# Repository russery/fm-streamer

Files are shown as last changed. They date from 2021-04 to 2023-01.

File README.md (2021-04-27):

# FM Streamer
Are there not a lot of good FM radio stations in your vicinity? Have you ever wished you could receive your hometown station on your FM radio while you're away? Well this is the project for you!

This is a simple ESP32/ESP8266 project that grabs an MP3 internet stream and bridges it to an FM transmitter, so that you can listen to the stream on your old-school FM radio.

# Setup
If you're on Linux or Mac (or any system with GNU Make installed), install [arduino-cli](https://github.com/arduino/arduino-cli). This project is set up to work out of the box with it, and this will save you having to set up the ESP32/ESP8266 and required libraries in your Arduino IDE.

1. Run `make config-tools` to install libraries and ESP32/ESP8266 core.
1. Rename `arduino_secrets.h.example` to `arduino_secrets.h` and change the wifi SSID and password in it to match the network you wish to attach to.
1. If you want to change the radio streams, edit them in the `StationList` struct in fm-streamer.ino.
1. Power on your board, connect its serial port to your computer, and see how the serial port comes up on your computer (e.g., `/dev/cu.usbserial-xxxx` or `COM1`, etc.). You'll use this value in the next step
1. Run `make program SERIAL_PORT=<serialport> MCU_TYPE=<esp32|esp8266>` (replacing \<serialport\> with the name of the serial port from the previous step, and using either "esp32" or "esp8266" as the MCU_TYPE) to compile the code and upload it to your board.

# Usage
Once you've followed the above steps and your board is programmed, the FM Streamer should connect to your wifi network, begin streaming the first mp3 stream in `StationList` (defined in webserver.h), and automatically broadcast over FM. There is a status output on the serial console that will tell you what's going on with the board as well.

I've implemented a web interface to the FM Streamer that allows you to control the station, volume, and transmit power of the FM Streamer. Note that this doesn't work on the ESP8266, as it runs out of RAM between the web server and audio streaming. However, it works well on the ESP32. Here's what it looks like:

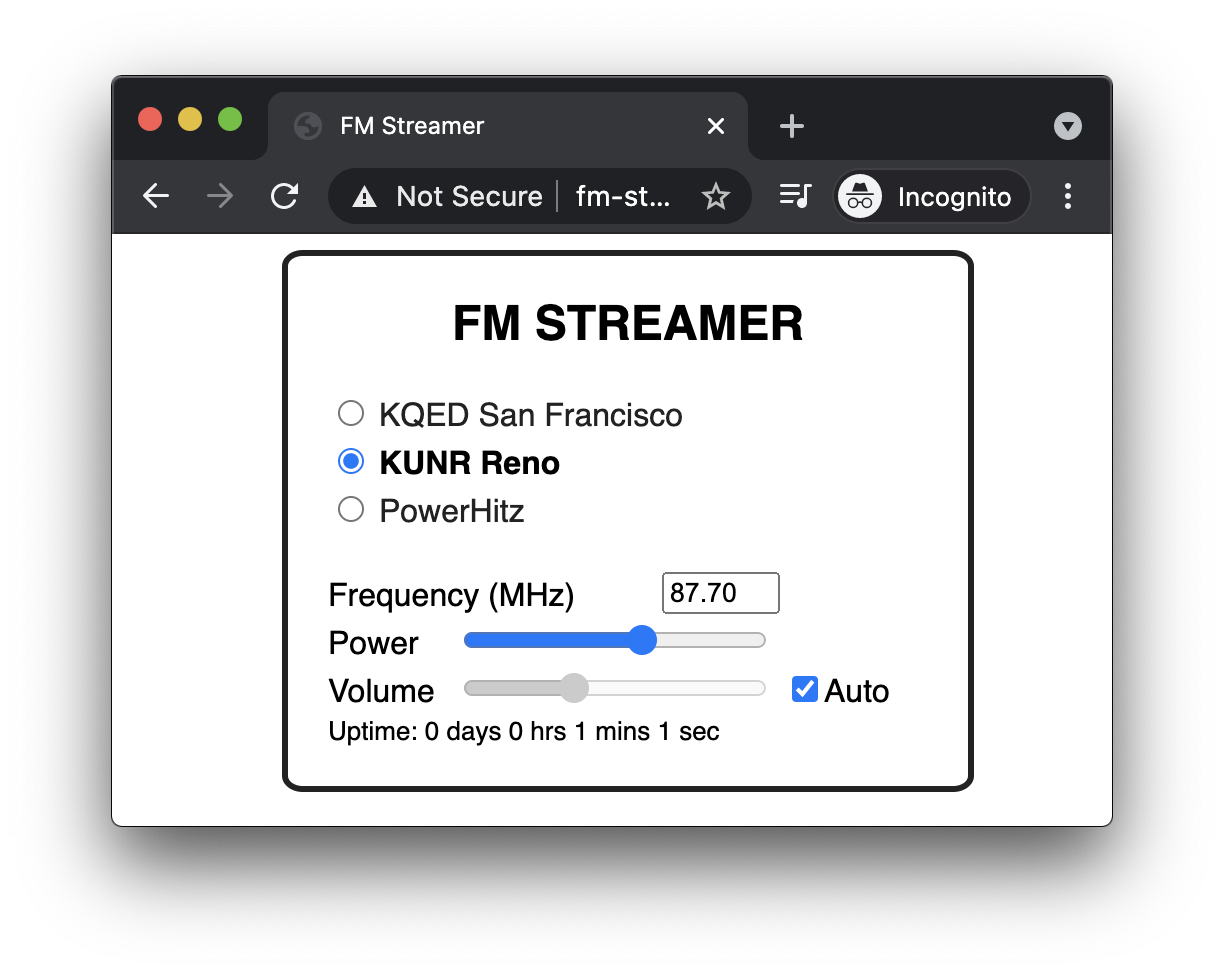
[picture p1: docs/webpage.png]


---

# Under the Hood
This project consists of three hardware components:
1. [ESP32 dev board](https://www.amazon.com/dp/B08D5ZD528) or [ESP3266 NodeMCU v1.0](https://www.amazon.com/gp/product/B010O1G1ES/)
1. [Adafruit UDA1334A I2S Stereo DAC breakout board](https://www.adafruit.com/product/3678)
1. [Adafruit Si4713 FM Transmitter breakout board](https://www.adafruit.com/product/1958)

## Hardware
These are wired together like so (for the ESP32):

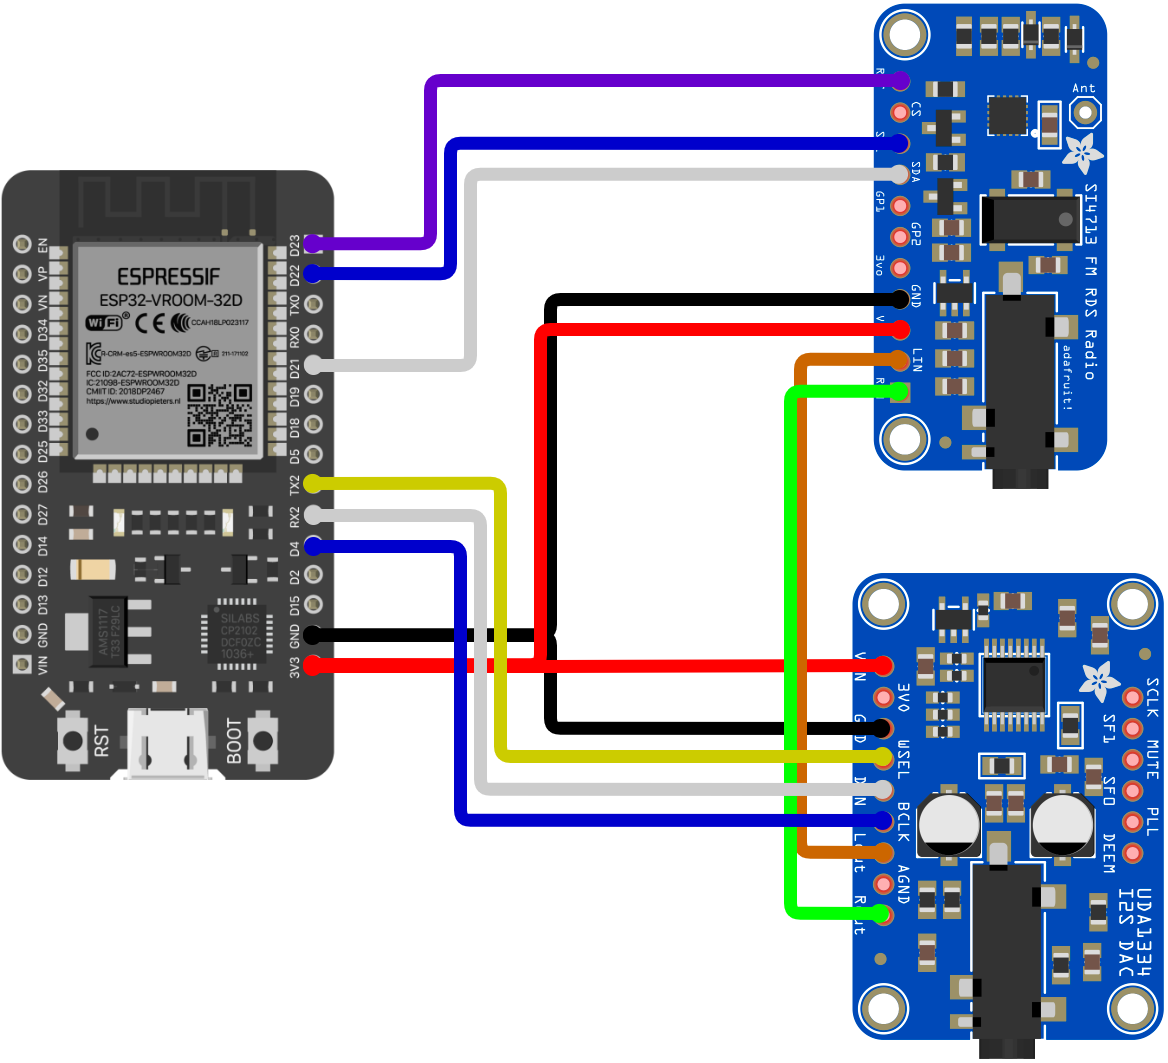
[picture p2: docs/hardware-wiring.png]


Everything is powered from the ESP32 board's 3.3V output. The Si4713 FM transmitter is connected to the ESP32 over I2C, the UDA1334 DAC is connected to it over I2S, and then the UDA1334 DAC outputs audio to the Si4713 transmitter via analog stereo audio.

I also wired a 4.7kΩ resistor from each of the DAC's analog audio outputs to GND to provide a bit of loading for it. I found that this helped reduce noise and clipping on the FM transmitter's input, although I did not experiment much with values or whether this is truly necessary.

## Software
The software makes use of the [ESP8266Audio](https://github.com/earlephilhower/ESP8266Audio) library and [Adafruit's Si4713](https://github.com/adafruit/Adafruit-Si4713-Library) driver. The webserver uses the [ESPAsynWebserver](https://github.com/me-no-dev/ESPAsyncWebServer/) library.

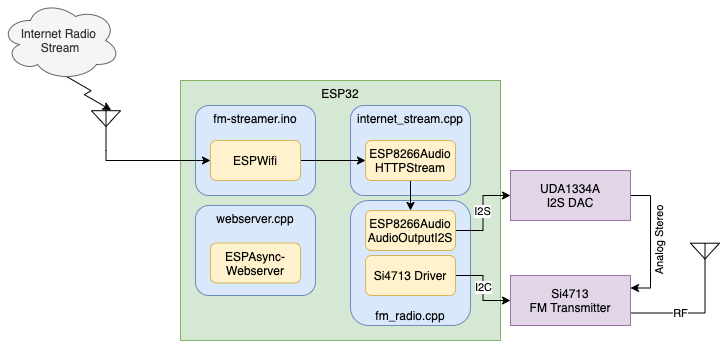
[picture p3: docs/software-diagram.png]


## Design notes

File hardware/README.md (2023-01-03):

# REV0 Hardware

## Hardware Errata
- USB connector backwards
- Silkscreen overlap on some components
- R21 puts chip in SPI mode... should be DNP'd

I2S format:
16-bit
Normal clock (rising edge)

TODO:
- fix hardware errata
- update top level readme with board images and latest hardware config

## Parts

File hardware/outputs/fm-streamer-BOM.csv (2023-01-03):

Reference | Quantity | Value | Footprint | Datasheet | MFG | MPN
C1 C13 C15 C18 | 4 | 0.1u | Capacitor_SMD:C_0402_1005Metric | ~ | Murata | GCM155R71C104KA55J
C4 C5 C6 C7 C8 C9 C10 C11 C17 | 9 | 22n | Capacitor_SMD:C_0402_1005Metric | ~ | Murata | GCM155R71E223KA55J
C2 C3 C12 C14 C16 C19 C20 C21 C22 C23 | 10 | 10u | Capacitor_SMD:C_0603_1608Metric | ~ | Murata | GRT188C81A106ME13D
J1 | 1 | USB_A | Connector_USB:USB_A_Plug_Molex_0480371000_90_deg_mount | ~ | Molex | 0480371000
L1 | 1 | 120n | Inductor_SMD:L_0603_1608Metric | ~ | Murata | LQW18ANR12G00D
R13 | 1 | 1 | Resistor_SMD:R_0402_1005Metric | ~ | Panasonic | ERJ-2BQJ1R0X
R1 R2 R14 R28 R29 R30 | 6 | 0 | Resistor_SMD:R_0402_1005Metric | ~ | Stackpole | RMCF0402ZT0R00
R15 R16 R18 R19 R20 R21 | 6 | 10k | Resistor_SMD:R_0402_1005Metric | ~ | Panasonic | ERJ-2RKF1002X
R24 R25 | 2 | 220k | Resistor_SMD:R_0402_1005Metric | ~ | Panasonic | ERJ-2RKF2203X
R4 R5 R6 R7 R8 R9 R10 R11 R17 R22 R23 R26 R27 | 13 | 100 | Resistor_SMD:R_0402_1005Metric | ~ | Panasonic | ERJ-2RKF1000X
R3 R12 | 2 | 4.7k | Resistor_SMD:R_0402_1005Metric | ~ | Panasonic | ERJ-2RKF4701X
TP1 | 1 | TestPoint | TestPoint:TestPoint_THTPad_D2.0mm_Drill1.0mm | ~ | ~ | ~
U1 | 1 | ESP32_DevKit_V1_DOIT | esp32_devkit_v1_doit:esp32_devkit_v1_doit | https://www.amazon.com/gp/product/B08D5ZD528/ | Amazon | B08D5ZD528
U2 | 1 | PCM1772PWR | footprints:PCM1772PWR |  | Texas Instruments | PCM1772PWR
U3 | 1 | SI4721 | SI4721:QFN-20-3X3MM |  | Silicon Labs | SI4721-B20-GM

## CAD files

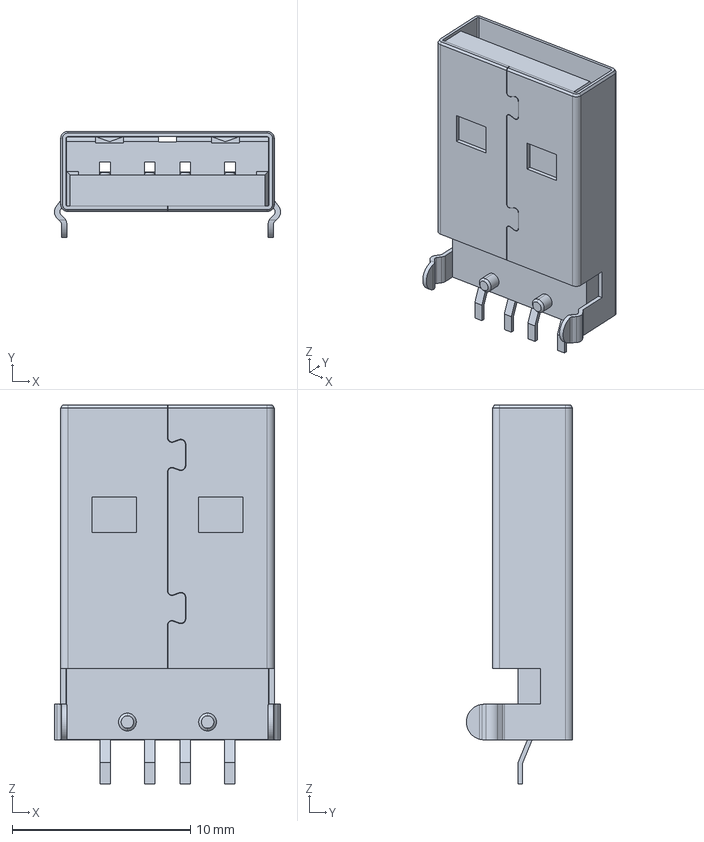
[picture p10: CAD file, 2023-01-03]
hardware/resources/molex/480371000.stp
12.7 x 5.97 x 21.3 mm

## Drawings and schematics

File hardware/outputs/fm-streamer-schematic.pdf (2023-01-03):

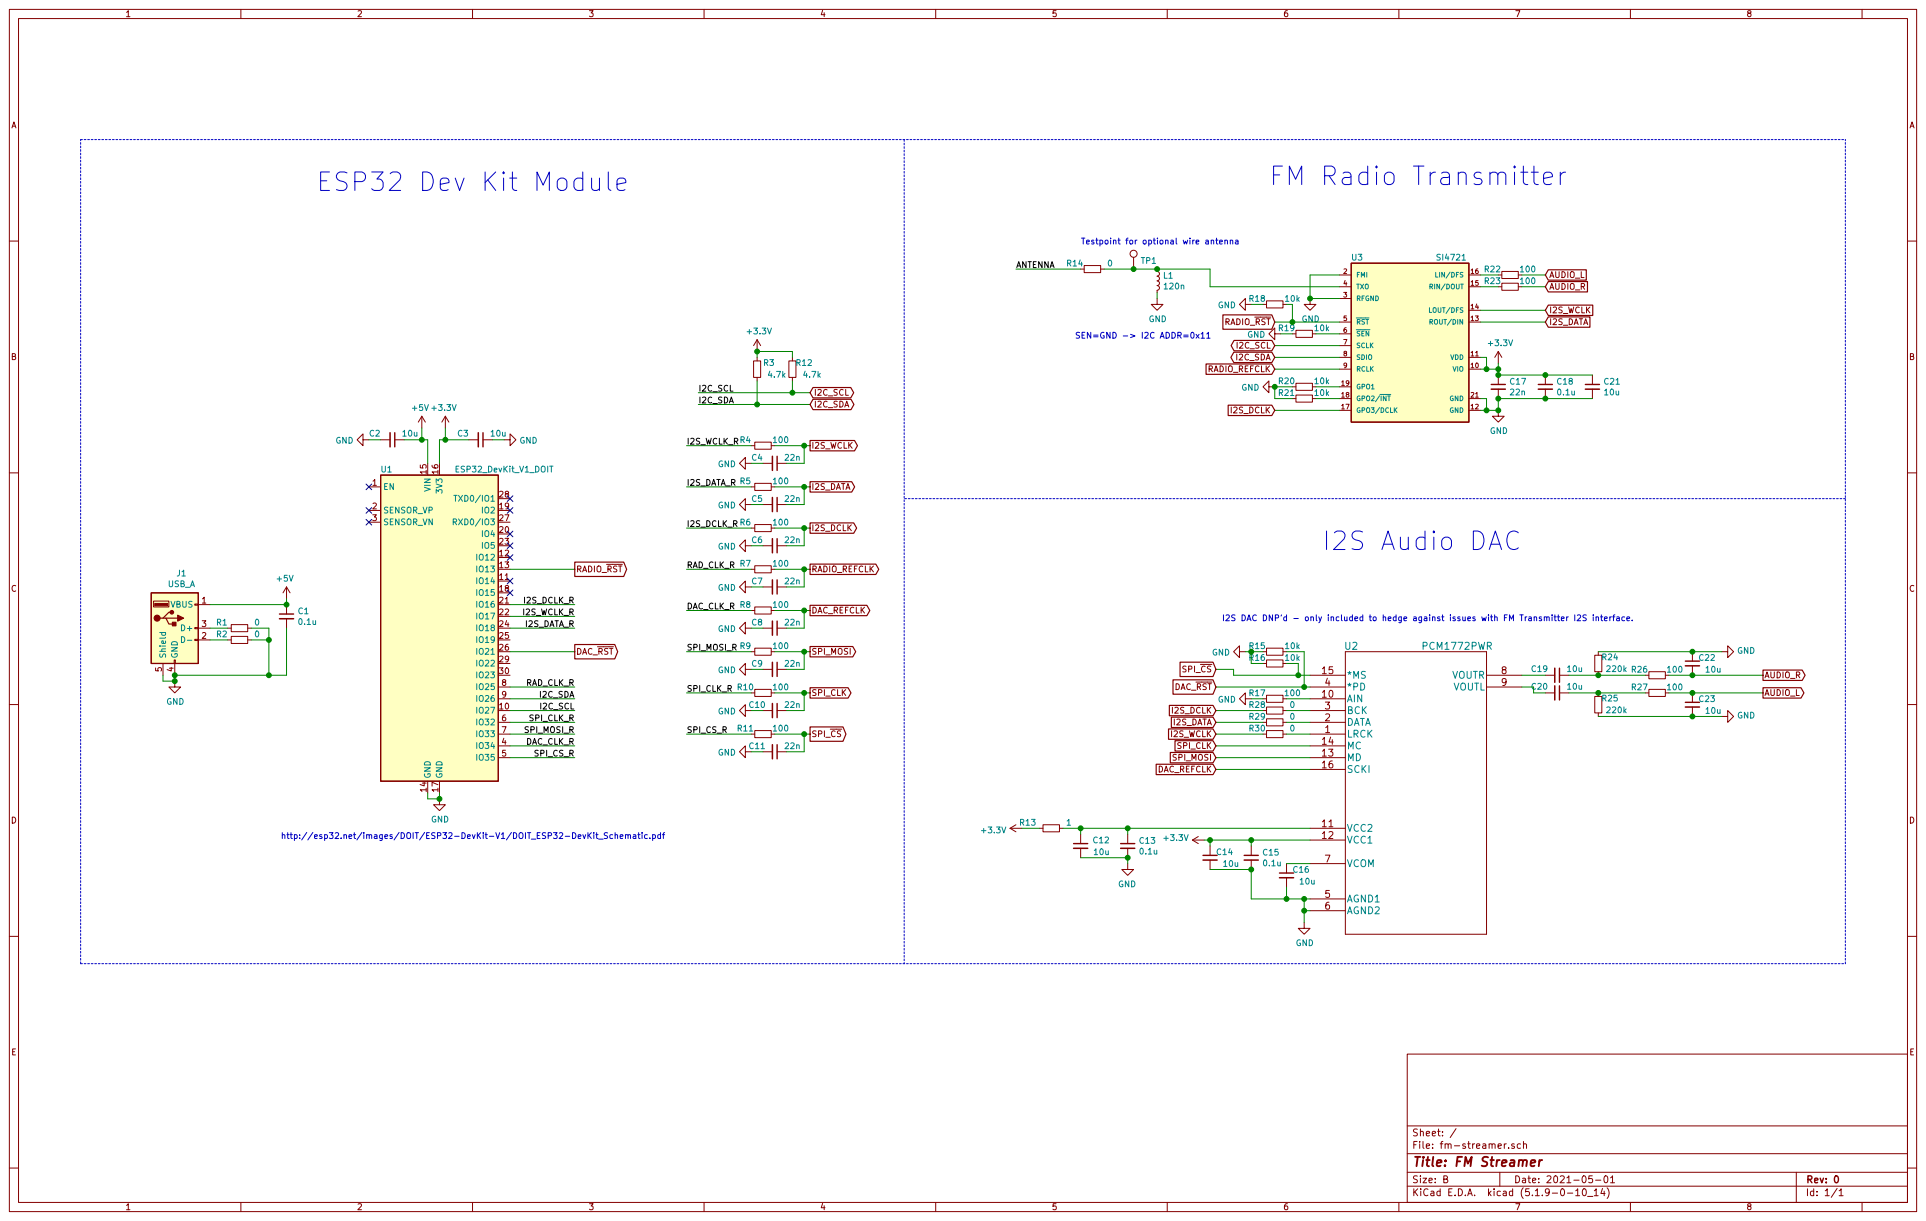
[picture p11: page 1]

SEN=GND -> I2C ADDR=0x11 Testpoint for optional wire antenna

I2S DAC DNPd - only included to hedge against issues with FM Transmitter I2S interface.

http://esp32.net/images/DOIT/ESP32-DevKit-V1/DOIT_ESP32-DevKit_Schematic.pdf

Id: 1/1 Title: FM Streamer File: fm-streamer.sch Sheet: /

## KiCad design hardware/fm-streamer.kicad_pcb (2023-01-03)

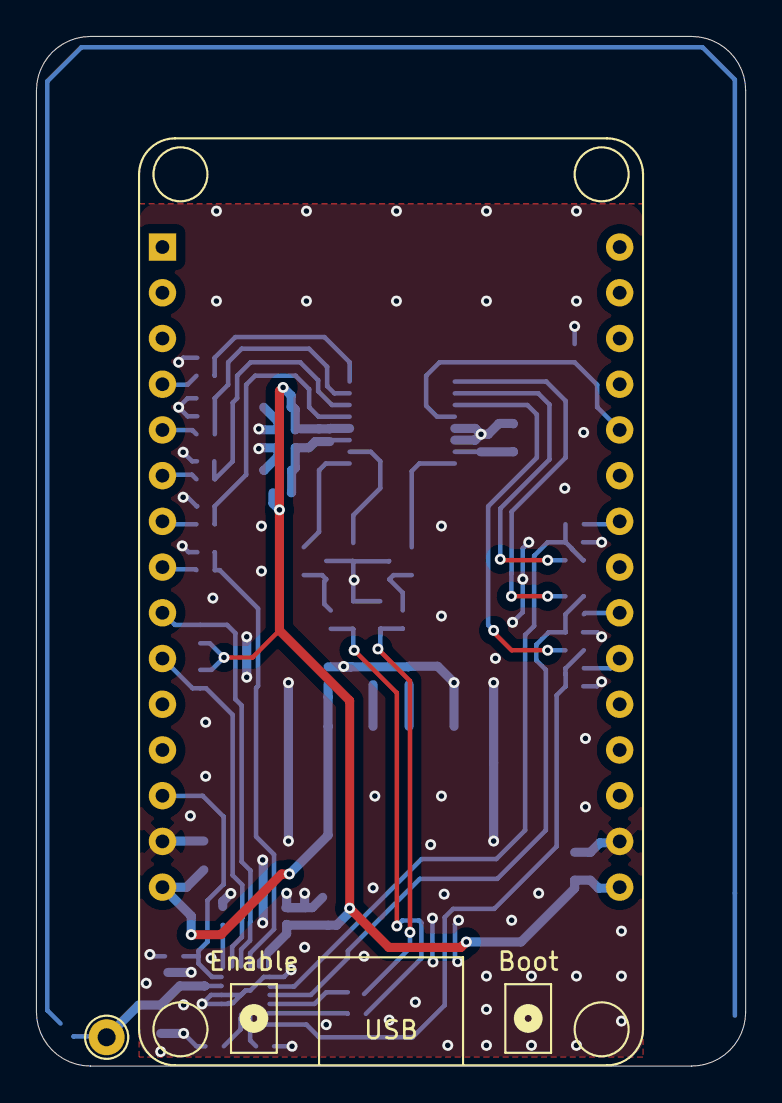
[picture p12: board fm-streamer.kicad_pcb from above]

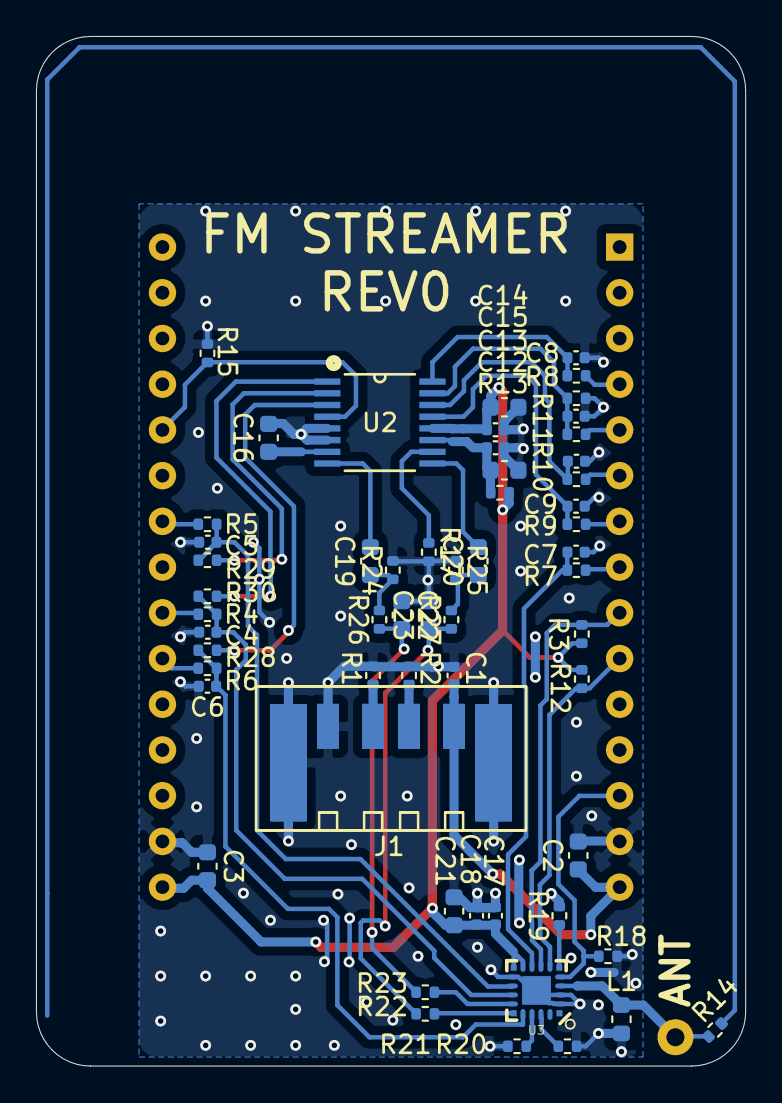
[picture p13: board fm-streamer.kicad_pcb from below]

Board: 2 copper layers, 39.4 x 57.2 mm, 61 parts (59 on the bottom side), 43 nets.

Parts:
C1, C13, C15, C18: 0.1u; C_0402_1005Metric
C2, C3, C12, C14, C16, C19, C20, C21, C22, C23: 10u; C_0603_1608Metric
C4, C5, C6, C7, C8, C9, C10, C11, C17: 22n; C_0402_1005Metric
J1, J1#2, J1#3: USB_A; USB_A_Plug_Molex_0480371000_90_deg_mount
L1: 120n; L_0603_1608Metric
R1, R2, R14, R28, R29, R30: 0; R_0402_1005Metric
R3, R12: 4.7k; R_0402_1005Metric
R4, R5, R6, R7, R8, R9, R10, R11, R17, R22, R23, R26, R27: 100; R_0402_1005Metric
R13: 1; R_0402_1005Metric
R15, R16, R18, R19, R20, R21: 10k; R_0402_1005Metric
R24, R25: 220k; R_0402_1005Metric
TP1: TestPoint; TestPoint_THTPad_D2.0mm_Drill1.0mm
U1: ESP32_DevKit_V1_DOIT; esp32_devkit_v1_doit
U2: PCM1772PWR
U3: SI4721; QFN-20-3X3MM

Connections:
+3V3: C3.2, C14.1, C15.1, C17.1, C18.1, C21.1, R3.2, R12.2, R13.2, U1.16, U2.12, U3.10, U3.11
+5V: C1.1, C2.1, J1.1, J1#2.1, J1#3.1, U1.15
/DAC_CLK_R: R8.2, U1.4
/I2S_DATA_R: R5.2, U1.24
/I2S_DCLK_R: R6.2, U1.21
/I2S_WCLK_R: R4.2, U1.22
/RAD_CLK_R: R7.2, U1.8
/SPI_CLK_R: R10.2, U1.6
/SPI_CS_R: R11.2, U1.5
/SPI_MOSI_R: R9.2, U1.7
AUDIO_L: C23.1, R22.1, R27.1
AUDIO_R: C22.2, R23.1, R26.1
DAC_REFCLK: C8.1, R8.1, U2.16
DAC_~RST~: R15.1, U1.26, U2.4
GND: C1.2, C2.2, C3.1, C4.2, C5.2, C6.2, C7.2, C8.2, C9.2, C10.2, C11.2, C12.2, C13.2, C14.2, C15.2, C16.2, C17.2, C18.2, C21.2, C22.1, C23.2, J1.4, J1.5, J1#2.4, J1#2.5, J1#3.4, J1#3.5, L1.2, R1.1, R2.1, R15.2, R16.2, R17.2, R18.2, R19.2, R20.2, R21.2, R24.2, R25.1, U1.14, U1.17, U2.5, U2.6, U3.2, U3.3, U3.12, U3.21
I2C_SCL: R12.1, U1.10, U3.7
I2C_SDA: R3.1, U1.9, U3.8
I2S_DATA: C5.1, R5.1, R29.2, U3.13
I2S_DCLK: C6.1, R6.1, R28.2, U3.17
I2S_WCLK: C4.1, R4.1, R30.2, U3.14
unnamed: C12.1, C13.1, R13.1, U2.11
unnamed: C16.1, U2.7
unnamed: C19.1, R24.1, R26.2
unnamed: C19.2, U2.8
unnamed: C20.1, R25.2, R27.2
unnamed: C20.2, U2.9
unnamed: J1.2, J1#2.2, J1#3.2, R2.2
unnamed: J1.3, J1#2.3, J1#3.3, R1.2
unnamed: L1.1, R14.1, TP1.1, U3.4
unnamed: R17.1, U2.10
unnamed: R19.1, U3.6
unnamed: R20.1, U3.19
unnamed: R21.1, U3.18
unnamed: R22.2, U3.16
unnamed: R23.2, U3.15
unnamed: R28.1, U2.3
unnamed: R29.1, U2.2
unnamed: R30.1, U2.1
RADIO_REFCLK: C7.1, R7.1, U3.9
RADIO_~RST~: R18.1, U1.13, U3.5
SPI_CLK: C10.1, R10.1, U2.14
SPI_MOSI: C9.1, R9.1, U2.13
SPI_~CS~: C11.1, R11.1, R16.1, U2.15

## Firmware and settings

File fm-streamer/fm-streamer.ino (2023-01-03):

/*
Streams an internet radio station over FM radio. This is accomplished
with an ESP8266 bridging audio to an I2S-enabled FM transmitter IC.

Copyright (C) 2021  Robert Ussery

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
You should have received a copy of the GNU General Public License
along with this program.  If not, see <https://www.gnu.org/licenses/>.
*/

#include "arduino_secrets.h"
#include "bsp.h"
#include "fm_radio.h"
#include "internet_stream.h"
#include "webserver.h"
#include <ArduinoOTA.h>
#if defined(ESP32)
#include <WiFi.h>
#elif defined(ESP8266)
#include <ESP8266WiFi.h>
#endif

extern const char WIFI_SSID[];
extern const char WIFI_PASSWORD[];
extern const char OTA_UPDATE_PWD[];
constexpr char RDS_STATION_NAME[] = "FMSTREAM"; // 8 characters max

FmRadio fm_radio;
InternetStream stream(10240, &(fm_radio.i2s_output));
Config cfg(Webserver::NUM_STATIONS);
Webserver webserver(&cfg);

void (*resetFunc)(void) = 0;

// cppcheck-suppress unusedFunction
void setup() {
  delay(500);
  Serial.begin(115200);
  Serial.println("\r\nFM Streamer Starting...\r\n\n");

  BSP::InitLED();

  WiFi.begin(WIFI_SSID, WIFI_PASSWORD);
  cfg.Start();
  webserver.Start();
  fm_radio.Start(RDS_STATION_NAME);

  ArduinoOTA.setHostname(Webserver::MDNS_ADDRESS);
  if (strlen(OTA_UPDATE_PWD) > 0)
    ArduinoOTA.setPassword(OTA_UPDATE_PWD);

  ArduinoOTA.onStart([]() { Serial.println("Start updating sketch"); });
  ArduinoOTA.onEnd([]() { Serial.println("\nFinished Updating"); });
  ArduinoOTA.onProgress([](unsigned int progress, unsigned int total) {
    Serial.printf("Progress: %u%%\r", (progress / (total / 100)));
  });
  ArduinoOTA.onError([](ota_error_t error) {
    Serial.printf("Error[%u]: ", error);
    if (error == OTA_AUTH_ERROR)
      Serial.println("Auth Failed");
    else if (error == OTA_BEGIN_ERROR)
      Serial.println("Begin Failed");
    else if (error == OTA_CONNECT_ERROR)
      Serial.println("Connect Failed");
    else if (error == OTA_RECEIVE_ERROR)
      Serial.println("Receive Failed");
    else if (error == OTA_END_ERROR)
      Serial.println("End Failed");
  });
}

void loop() {
  static enum LoopState {
    ST_WIFI_CONNECT,
    ST_STREAM_START,
    ST_STREAM_CONNECTING,
    ST_STREAMING
  } state = ST_WIFI_CONNECT;
  static unsigned long stream_start_time_ms = 0;

  switch (state) {
  case ST_WIFI_CONNECT:
    if (WiFi.status() == WL_CONNECTED) {
      state = ST_STREAM_START;
      webserver.StartMdns();
      ArduinoOTA.begin();
    }
    break;
  case ST_STREAM_START:
    fm_radio.SetI2SInputEnable(false); // Disable I2S input
    stream.OpenUrl(webserver.GetCurrentStream().URL);
    fm_radio.SetRdsText(webserver.GetCurrentStream().Name);
    BSP::SetLED(false);
    state = ST_STREAM_CONNECTING;
    stream_start_time_ms = millis();
    break;
  case ST_STREAM_CONNECTING:
    if (stream.Loop()) {
      state = ST_STREAMING;
      fm_radio.SetI2SInputEnable(true); // Enable I2S input
    } else if (millis() - stream_start_time_ms > 30000) {
      resetFunc(); // Timed out trying to connect, try resetting
    }
    break;
  case ST_STREAMING:
    static unsigned long last_autovol_ms = 0;
    if ((cfg.GetAutoVolume()) && (millis() - last_autovol_ms > 1000)) {
      cfg.SetVolume(fm_radio.GetVolume()); // Update value in config
      last_autovol_ms = millis();
      fm_radio.DoAutoSetVolume();
    }
    BSP::SetLED(true);
    if (!stream.Loop()) {
      stream.Flush();
      state = ST_STREAM_START;
    }
    break;
  }

  static unsigned long last_print_ms = 0;
  if (millis() - last_print_ms > 1000) {
    last_print_ms = millis();
    Serial.print(F("\r\n\n\n"));
    Serial.print(F("\r\n-----------------------------------"));
    Serial.print(F("\r\n        fm-streamer status"));
    Serial.print(F("\r\n-----------------------------------"));
    unsigned long sec = millis() / 1000;
    Serial.printf_P((PGM_P) "\r\nUptime: %d days %d hrs %d mins %d sec",
                    sec / 86400, (sec / 3600) % 24, (sec / 60) % 60, sec % 60);
    Serial.printf_P((PGM_P) "\r\nSSID: \"%s\"", WiFi.SSID().c_str());
    Serial.printf_P((PGM_P) "\r\nIP Address: %s DNS: %s%s",
                    WiFi.localIP().toString().c_str(),
                    (webserver.IsMdnsActive()) ? webserver.MDNS_ADDRESS
                                               : (PGM_P)("<inactive>"),
                    (webserver.IsMdnsActive()) ? (PGM_P)(".local") : "");
    Serial.print(F("\r\nStatus: "));
    switch (state) {
    case ST_WIFI_CONNECT:
      Serial.print(F("Connecting to Wifi"));
      break;
    case ST_STREAM_START:
      Serial.print(F("Starting internet stream"));
      break;
    case ST_STREAM_CONNECTING:
      Serial.print(F("Connecting to internet stream"));
      break;
    case ST_STREAMING:
      Serial.print(F("Streaming from internet"));
      break;
    }
    Serial.printf_P((PGM_P) "\r\nStation: %s",
                    webserver.GetCurrentStream().Name);
    Serial.printf_P(
        (PGM_P) "\r\nFreq: %5.2fMHz  Power: %3d%%   Volume: %3d%%%s",
        float(fm_radio.GetFreq()) / 1000.0f, fm_radio.GetTxPower(),
        fm_radio.GetVolume(), (cfg.GetAutoVolume()) ? "(Auto)" : "");
  }

  webserver.Loop();
  if (webserver.IsConfigChanged()) {
    static uint previous_station = cfg.GetStation();
    uint curr_station = cfg.GetStation();
    if (curr_station != previous_station) {
      previous_station = curr_station;   // User changed station
      fm_radio.SetI2SInputEnable(false); // disable I2S input
      stream.Flush();
      state = ST_STREAM_START;
    }
    if (!cfg.GetAutoVolume()) {
      fm_radio.SetVolume(cfg.GetVolume());
    }
    fm_radio.SetFreq(cfg.GetFreqkHz());
    fm_radio.SetTxPower(cfg.GetPower());
  }

  ArduinoOTA.handle();
  BSP::Loop();

  yield(); // Make sure WiFi can do its thing.
}

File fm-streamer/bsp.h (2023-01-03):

/*
Includes pin definitions and other hardware-specific things.

Copyright (C) 2021  Robert Ussery

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
You should have received a copy of the GNU General Public License
along with this program.  If not, see <https://www.gnu.org/licenses/>.
*/

#ifndef __BSP_H
#define __BSP_H

#include <Arduino.h>

#define HARDWARE_REV0

class BSP {
public:
#if defined(ESP32)
  // Status LED and states:
  static constexpr char LED_STREAMING_PIN PROGMEM = 2;
  static constexpr char LED_OFF PROGMEM = LOW;
  static constexpr char LED_ON PROGMEM = HIGH;

#elif defined(ESP8266)
  // Status LED and states:
  static constexpr char LED_STREAMING_PIN PROGMEM = 16;
  static constexpr char LED_OFF PROGMEM = HIGH;
  static constexpr char LED_ON PROGMEM = LOW;
#endif // ESP32 / ESP8266

#if defined(HARDWARE_PROTO_ESP8266)
  static constexpr uint RADIO_RESET_PIN PROGMEM = 12;
  static constexpr uint SI47XX_CHIP_VERSION = 13; // SI4713
  static constexpr uint SI47xx_I2C_ADDR PROGMEM = 0x63;

  static constexpr uint I2S_BCLK_PIN PROGMEM = 15;
  static constexpr uint I2S_WCLK_PIN PROGMEM = 2;
  static constexpr uint I2S_DATA_PIN PROGMEM = 3;

  static constexpr uint I2C_SDA_PIN PROGMEM = 4;
  static constexpr uint I2C_SCL_PIN PROGMEM = 5;

#elif defined(HARDWARE_PROTO_ESP32)
  static constexpr uint RADIO_RESET_PIN PROGMEM = 23;
  static constexpr uint SI47XX_CHIP_VERSION = 13; // SI4713
  static constexpr uint SI47xx_I2C_ADDR PROGMEM = 0x63;

  static constexpr uint I2S_BCLK_PIN PROGMEM = 4;
  static constexpr uint I2S_WCLK_PIN PROGMEM = 17;
  static constexpr uint I2S_DATA_PIN PROGMEM = 16;

  static constexpr uint I2C_SDA_PIN PROGMEM = 21;
  static constexpr uint I2C_SCL_PIN PROGMEM = 22;

#elif defined(HARDWARE_REV0)
  static constexpr uint RADIO_RESET_PIN PROGMEM = 13;
  static constexpr uint RADIO_CLK_PIN PROGMEM = 25;
  static constexpr uint SI47XX_CHIP_VERSION = 21; // SI4721
  static constexpr uint SI47xx_I2C_ADDR PROGMEM = 0x11;

  static constexpr uint I2S_BCLK_PIN PROGMEM = 16;
  static constexpr uint I2S_WCLK_PIN PROGMEM = 17;
  static constexpr uint I2S_DATA_PIN PROGMEM = 18;

  static constexpr uint I2C_SDA_PIN PROGMEM = 26;
  static constexpr uint I2C_SCL_PIN PROGMEM = 27;

  // static constexpr uint DAC_RESET_PIN PROGMEM = 21;
  // static constexpr uint DAC_CLK_PIN PROGMEM = 34;

  // static constexpr uint SPI_SCK_PIN PROGMEM = 32;
  // static constexpr uint SPI_MOSI_PIN PROGMEM = 33;
  // static constexpr uint DAC_SPI_CS PROGMEM = 35;

#endif // Hardware versions

  static void StartSi47xxClock(uint freq_hz);
  static void InitLED(void);
  static void SetLED(bool state);
  static void Loop(void);

private:
  static constexpr uint32_t LED_MAX_BRIGHTNESS PROGMEM = 100;
  static constexpr uint32_t LED_MIN_BRIGHTNESS PROGMEM = 5;
  static bool LED_on_;
};

#endif // __BSP_H

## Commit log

2021-04-08 arduino-cli bash script and files roughed out
2021-04-14 Removed arduino-cli config file and made config-tools target to auto-gen
2021-04-16 Tweaked buffer size to debug heap corruption issue
    [fm-streamer.ino]
2021-04-19 Added PID-control of audio levels, added #define to remove webserver
2021-04-19 tuned PID loop, added LED indicator for streaming
2021-04-21 Added auto-reset and changed library imports to be consistent with implementation
    [fm-streamer.ino]
2021-04-21 stubbed out kicad
    [fm-streamer.kicad_pcb, fm-streamer.sch]
2021-04-21 minor cleanup and fixes
    [fm-streamer.ino]
2021-04-22 Added ESP32 support
2021-04-22 Updated README with ESP32 references
2021-04-25 Everything working on ESP32 hardware
2021-04-26 fixed issue with changing stations
    [fm-streamer.ino]
2021-04-27 Updated docs for ESP32
2021-04-27 OTA updates working, although not compatible with arduino-cli (yet)
    [fm-streamer.ino]
2021-05-01 debugged operation and retuned autovolume PID loop
2021-05-02 roughing out schematics
    [fm-streamer.sch]
2021-05-02 schematics nominally finished, moving on to PCB
    [fm-streamer.sch]
2021-05-02 rough placement and routing complete, needs cleanup
    [fm-streamer.sch]
2021-05-03 cleaning up routing
    [fm-streamer.kicad_pcb, fm-streamer.sch]
2021-05-03 added 3D body for Molex USB connector, layout cleanup
    [480371000.stp, fm-streamer.kicad_pcb]
2021-05-04 ready for fab quote
    [fm-streamer-B_Cu.gbr, fm-streamer-B_Mask.gbr, fm-streamer-B_SilkS.gbr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]
2021-05-05 Rev0 out to fab
    [fm-streamer-BOM.csv, fm-streamer.kicad_pcb, fm-streamer.sch]
2021-05-05 fixed some build issues with ESP8266 and got hardware compile switches working
    [bsp.h, config.cpp, fm-streamer.ino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]
2021-05-05 made BSP a class with static members, added PWM output for radio clock (untested)
2021-05-19 cleanup and made LED glow

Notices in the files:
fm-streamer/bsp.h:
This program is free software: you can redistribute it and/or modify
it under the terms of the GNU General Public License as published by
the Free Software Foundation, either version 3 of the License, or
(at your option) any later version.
